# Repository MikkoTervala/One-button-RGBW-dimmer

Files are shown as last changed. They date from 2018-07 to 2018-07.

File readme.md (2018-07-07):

This dimmer was built for a car. It uses a single button to cycle between colors. 
Other features include:

- 6 RGBW outputs.
- Individually fused channels, 4 polyfuses for each output, 24 fuses in total.
- OTA update over wifi, starts to OTA mode by holding button while starting car.

Microcontroller is the ESP8266 and code is written in arduino. Kicad is used for the PCB design.

Imgur

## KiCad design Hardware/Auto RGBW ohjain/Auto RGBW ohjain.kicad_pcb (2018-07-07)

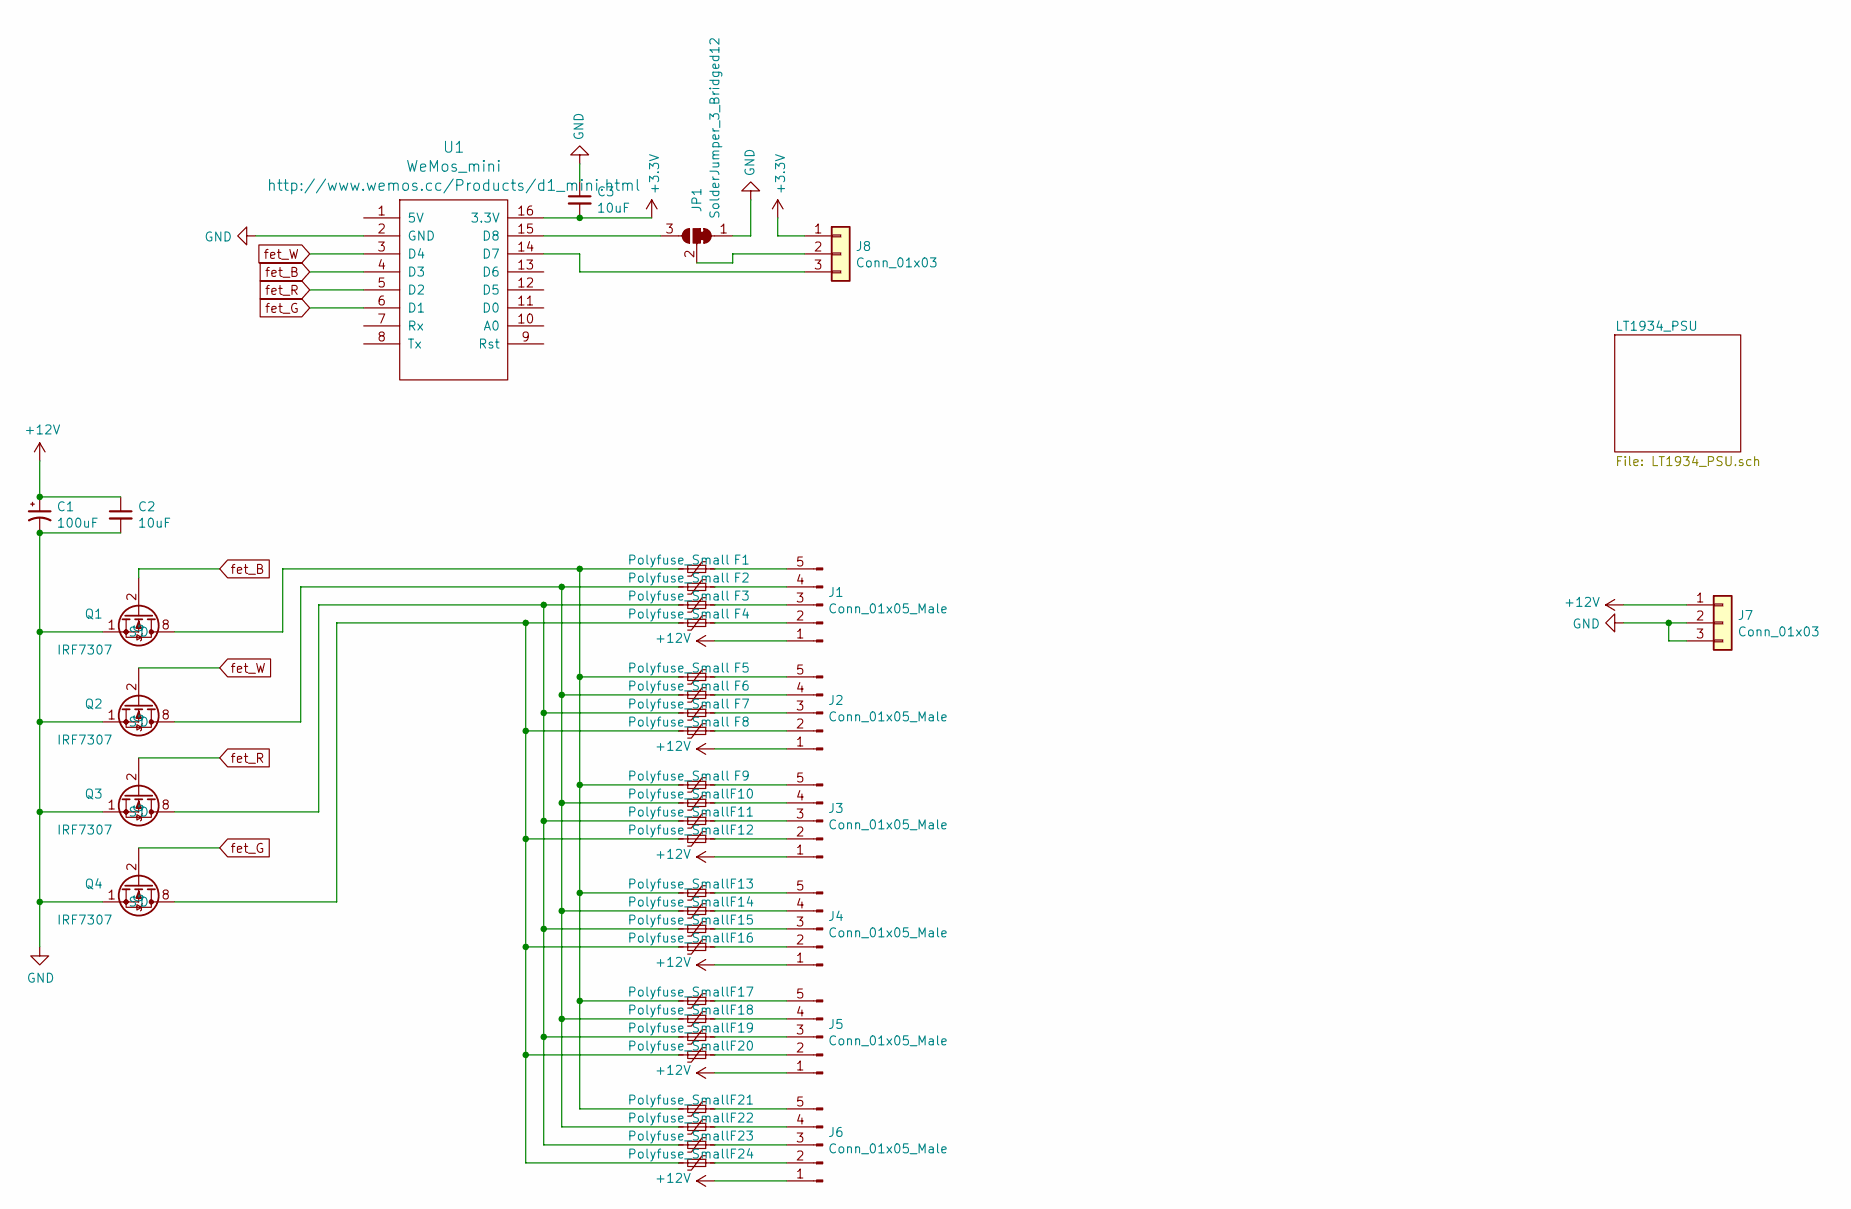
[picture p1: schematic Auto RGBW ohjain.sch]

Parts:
C1: 100uF; CP_Radial_D6.3mm_P2.50mm
C2, C3: 10uF; C_1210_3225Metric
F1, F2, F3, F4, F5, F6, F7, F8, F9, F10, F11, F12, F13, F14, F15, F16, F17, F18, F19, F20, F21, F22, F23, F24: Polyfuse_Small; Fuse_1206_3216Metric; Manufacture Part Number 1206L035/16YR; LCSC Part Number C126817
J1, J2, J3, J4, J5, J6: Conn_01x05_Male; JST_XH_B05B-XH-A_1x05_P2.50mm_Vertical
J7, J8: Conn_01x03; WJ250B-3.50-3P
JP1: SolderJumper_3_Bridged12; SolderJumper-3_P1.3mm_Bridged12_RoundedPad1.0x1.5mm
Q1, Q2, Q3, Q4: IRF7307; SO-8_5.3x6.2mm_P1.27mm
U1: WeMos_mini; D1_mini_board

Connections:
+3V3: C3.2, J8.1, U1.16 (3.3V); also elsewhere on the board
+12V: C1.1, C2.1, J1.1, J2.1, J3.1, J4.1, J5.1, J6.1, J7.1; also elsewhere on the board
GND: C1.2, C2.2, C3.1, J7.2, J7.3, JP1.1 (A), Q1.1 (S), Q2.1 (S), Q3.1 (S), Q4.1 (S), U1.2 (GND); also elsewhere on the board
unnamed: F1.1, J1.5
unnamed: F1.2, F5.2, F9.2, F13.2, F17.2, F21.2, Q1.7 (D), Q1.8 (D)
unnamed: F2.1, J1.4
unnamed: F3.1, J1.3
unnamed: F4.1, J1.2
unnamed: F5.1, J2.5
unnamed: F6.1, J2.4
unnamed: F7.1, J2.3
unnamed: F8.1, J2.2
unnamed: F9.1, J3.5
unnamed: F10.1, J3.4
unnamed: F2.2, F6.2, F10.2, F14.2, F18.2, F22.2, Q2.7 (D), Q2.8 (D)
unnamed: F11.1, J3.3
unnamed: F3.2, F7.2, F11.2, F15.2, F19.2, F23.2, Q3.7 (D), Q3.8 (D)
unnamed: F12.1, J3.2
unnamed: F4.2, F8.2, F12.2, F16.2, F20.2, F24.2, Q4.7 (D), Q4.8 (D)
unnamed: F13.1, J4.5
unnamed: F14.1, J4.4
unnamed: F15.1, J4.3
unnamed: F16.1, J4.2
unnamed: F17.1, J5.5
unnamed: F18.1, J5.4
unnamed: F19.1, J5.3
unnamed: F20.1, J5.2
unnamed: F21.1, J6.5
unnamed: F22.1, J6.4
unnamed: F23.1, J6.3
unnamed: F24.1, J6.2
unnamed: J8.2, JP1.2 (C)
unnamed: J8.3, U1.14 (D7)
unnamed: JP1.3 (B), U1.15 (D8)
fet_B: Q1.2 (G), U1.4 (D3)
fet_G: Q4.2 (G), U1.6 (D1)
fet_R: Q3.2 (G), U1.5 (D2)
fet_W: Q2.2 (G), U1.3 (D4)

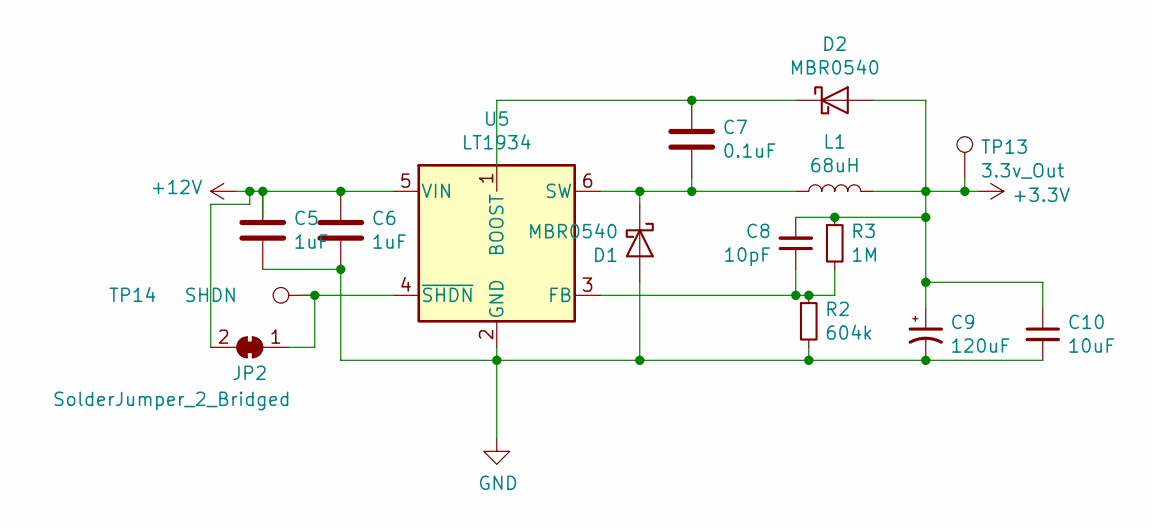
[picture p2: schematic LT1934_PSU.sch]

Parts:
C5, C6: 1uF; C_1206_3216Metric
C7: 0.1uF; C_0805_2012Metric; Manufacture Part Number GRM2165C2A101JA01D; LCSC Part Number C97903
C8: 10pF; C_0805_2012Metric
C9: 120uF; CP_Radial_D6.3mm_P2.50mm
C10: 10uF; C_1210_3225Metric
D1, D2: MBR0540; D_SOD-123; Manufacture Part Number MBR0540L-CA2-R; LCSC Part Number C89706
JP2: SolderJumper_2_Bridged; SolderJumper-2_P1.3mm_Bridged_RoundedPad1.0x1.5mm
L1: 68uH; L_SUMIDA_CDRH5D28
R2: 604k; R_0805_2012Metric; Manufacture Part Number 0805W8F6043T5E; LCSC Part Number C17776
R3: 1M; R_0805_2012Metric; Manufacture Part Number 0805W8F1004T5E; LCSC Part Number C17514
TP13: 3.3v_Out; TestPoint_Loop_D2.50mm_Drill1.0mm
TP14: SHDN; TestPoint_Pad_D1.0mm
U5: LT1934; SOT-23-6

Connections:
+3V3: C8.2, C9.1, C10.1, D2.2 (A), L1.2, R3.1, TP13.1; also elsewhere on the board
+12V: C5.2, C6.2, JP2.2 (B), U5.5 (VIN); also elsewhere on the board
GND: C5.1, C6.1, C9.2, C10.2, D1.2 (A), R2.2, U5.2 (GND); also elsewhere on the board
unnamed: C7.1, D2.1 (K), U5.1 (BOOST)
unnamed: C7.2, D1.1 (K), L1.1, U5.6 (SW)
unnamed: C8.1, R2.1, R3.2, U5.3 (FB)
unnamed: JP2.1 (A), TP14.1, U5.4 (~SHDN)

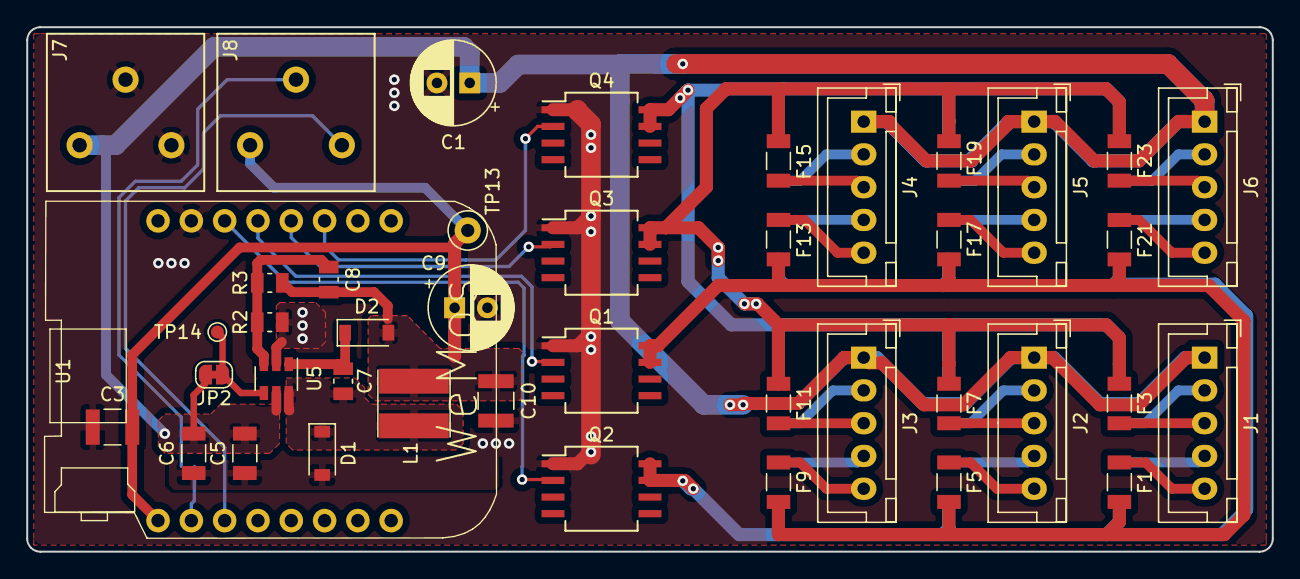
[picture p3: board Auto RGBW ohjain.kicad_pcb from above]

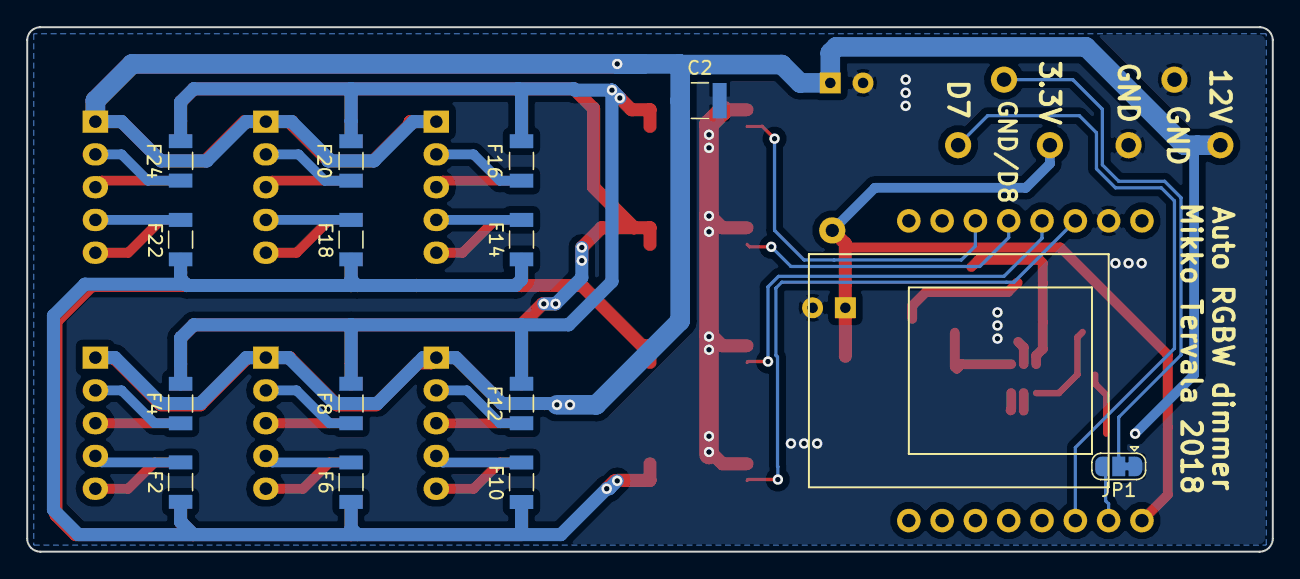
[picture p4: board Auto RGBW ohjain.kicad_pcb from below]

Board: 2 copper layers, 95.0 x 40.0 mm, 56 parts (14 on the bottom side), 42 nets.

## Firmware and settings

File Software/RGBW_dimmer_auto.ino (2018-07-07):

#include <ESP8266WiFi.h>
#include <ESP8266mDNS.h>
#include <WiFiUdp.h>
#include <ArduinoOTA.h>

// Wifi credentials for OTA update
const char* ssid = "WIFI SSID for OTA";
const char* password = "PASSWORD";


#define R D2
#define G D1
#define B D3
#define W D4
#define button D7

int RGBWarray[4] = { 500, 500, 500, 500 };	// Brightness we want to display
int RGBWarrayReal[4] = { 0, 0, 0, 0 };		// Actual pwm value at the moment

bool onOff = 1;			// Is light on or off
int colorSelect = 0;	// Selected color number

long buttonTimer = 0;
long longPressTime = 400;
boolean buttonActive = false;
boolean longPressActive = false;
boolean singlePress = false;
boolean longPress = false;

unsigned long dimmerPreviousMillis = 0;
const long dimmerInterval = 0;

// Writes PWM values, used in debugging without dimming
void debugWritePwm()
{
	analogWrite(R, RGBWarray[0]);
	analogWrite(G, RGBWarray[1]);
	analogWrite(B, RGBWarray[2]);
	analogWrite(W, RGBWarray[3]);
}

// Writes PWM values
void writePwm() 
{
	analogWrite(R, RGBWarrayReal[0]);
	analogWrite(G, RGBWarrayReal[1]);
	analogWrite(B, RGBWarrayReal[2]);
	analogWrite(W, RGBWarrayReal[3]);
}

// This checks if we want to change the brightness of any channel, and changes the value smoothly if needed
void dimmer()
{
	unsigned long currentMillis = millis();
	if (currentMillis - dimmerPreviousMillis >= dimmerInterval)
	{
		dimmerPreviousMillis = currentMillis;
		for (int i = 0; i <= 3; i++)
		{
			if (RGBWarray[i] > RGBWarrayReal[i])
			{
				RGBWarrayReal[i] ++;
			}
			if (RGBWarray[i] < RGBWarrayReal[i])
			{
				RGBWarrayReal[i] --;
			}
		}
		writePwm();
	}
}

// Checks if any buttons pressed, and updates statuses
void buttonPress()
{
	longPress = false;
	singlePress = false;

	if (digitalRead(button) == HIGH) {
		//Serial.println("Button pressed");
		if (buttonActive == false) {
			buttonActive = true;
			buttonTimer = millis();
		}
		if ((millis() - buttonTimer > longPressTime) && (longPressActive == false)) {
			longPressActive = true;
			longPress = true;
		}
	}
	else {
		if (buttonActive == true) {
			Serial.println("2");
			if (longPressActive == true) {
				longPressActive = false;
			}
			else {
				singlePress = true;
			}
			buttonActive = false;
		}
	}
}

// Ota mode waits for ota software update
void otaMode()
{
	Serial.begin(115200);
	Serial.println("Booting");
	WiFi.mode(WIFI_STA);
	WiFi.begin(ssid, password);
	while (WiFi.waitForConnectResult() != WL_CONNECTED) {
		Serial.println("Connection Failed! Rebooting...");
		delay(5000);
		ESP.restart();
	}
	// Port defaults to 8266
	// ArduinoOTA.setPort(8266);

	// Hostname defaults to esp8266-[ChipID]
	// ArduinoOTA.setHostname("myesp8266");

	// No authentication by default
	// ArduinoOTA.setPassword("admin");

	// Password can be set with it's md5 value as well
	// MD5(admin) = 21232f297a57a5a743894a0e4a801fc3
	// ArduinoOTA.setPasswordHash("21232f297a57a5a743894a0e4a801fc3");

	ArduinoOTA.onStart([]() {
		String type;
		if (ArduinoOTA.getCommand() == U_FLASH)
			type = "sketch";
		else // U_SPIFFS
			type = "filesystem";

		// NOTE: if updating SPIFFS this would be the place to unmount SPIFFS using SPIFFS.end()
		Serial.println("Start updating " + type);
	});
	ArduinoOTA.onEnd([]() {
		Serial.println("\nEnd");
		RGBWarray[0] = 100;
		RGBWarray[1] = 800;
		RGBWarray[2] = 100;
		RGBWarray[3] = 100;
		debugWritePwm();
		delay(2000);
	});
	ArduinoOTA.onProgress([](unsigned int progress, unsigned int total) {
		Serial.printf("Progress: %u%%\r", (progress / (total / 100)));
		RGBWarray[0] = 100;
		RGBWarray[1] = 100;
		RGBWarray[2] = 800;
		RGBWarray[3] = 100;
		debugWritePwm();
		delay(200);
	});
	ArduinoOTA.onError([](ota_error_t error) {
		Serial.printf("Error[%u]: ", error);
		if (error == OTA_AUTH_ERROR) Serial.println("Auth Failed");
		else if (error == OTA_BEGIN_ERROR) Serial.println("Begin Failed");
		else if (error == OTA_CONNECT_ERROR) Serial.println("Connect Failed");
		else if (error == OTA_RECEIVE_ERROR) Serial.println("Receive Failed");
		else if (error == OTA_END_ERROR) Serial.println("End Failed");
		RGBWarray[0] = 800;
		RGBWarray[1] = 100;
		RGBWarray[2] = 100;
		RGBWarray[3] = 100;
		debugWritePwm();
		delay(2000);
	});
	ArduinoOTA.begin();
	Serial.println("Ready");
	Serial.print("IP address: ");
	Serial.println(WiFi.localIP());

	while (true)
	{
		Serial.println("Ota loop");
		//delay(500);
		ArduinoOTA.handle();
		RGBWarray[0] = 200;
		RGBWarray[1] = 200;
		RGBWarray[2] = 200;
		RGBWarray[3] = 200;
		debugWritePwm();
		delay(500);
		RGBWarray[0] = 10;
		RGBWarray[1] = 10;
		RGBWarray[2] = 10;
		RGBWarray[3] = 10;
		debugWritePwm();
		delay(500);
		if (digitalRead(button) == HIGH)
		{
			delay(500);
			if (digitalRead(button) == HIGH)
			{
				RGBWarray[0] = 800;
				RGBWarray[1] = 100;
				RGBWarray[2] = 100;
				RGBWarray[3] = 100;
				debugWritePwm();
				delay(2000);
				ESP.restart();
			}
		}
	}
}



void setup()
{
	Serial.begin(115200);
	delay(2000);
	Serial.println("Started");
	pinMode(R, OUTPUT);
	pinMode(G, OUTPUT);
	pinMode(B, OUTPUT);
	pinMode(W, OUTPUT);
	pinMode(button, INPUT);
	delay(500);
	if (digitalRead(button) == HIGH)
	{
		Serial.println("Ota mode!");
		delay(500);
		otaMode();
	}
}

void loop()
{
	dimmer();
	buttonPress();

	if (singlePress)
	{
		Serial.println("single press true");
		colorSelect++;
		if (colorSelect > 4)
		{
			colorSelect = 0;
		}
		Serial.println(colorSelect);
	}
	if (longPress)
	{
		onOff = !onOff;
	} 

	switch (colorSelect)
	{
	case 0:
		RGBWarray[0] = 1000;
		RGBWarray[1] = 0;
		RGBWarray[2] = 1000;
		RGBWarray[3] = 500;
		break;
	case 1:
		RGBWarray[0] = 200;
		RGBWarray[1] = 0;
		RGBWarray[2] = 200;
		RGBWarray[3] = 100;
		break;
	case 2:
		RGBWarray[0] = 1000;
		RGBWarray[1] = 0;
		RGBWarray[2] = 0;
		RGBWarray[3] = 100;
		break;
	case 3:
		RGBWarray[0] = 0;
		RGBWarray[1] = 0;
		RGBWarray[2] = 1000;
		RGBWarray[3] = 300;
		break;
	case 4:
		RGBWarray[0] = 0;
		RGBWarray[1] = 0;
		RGBWarray[2] = 0;
		RGBWarray[3] = 500;
		break;
	default:
		break;
	}

	if (onOff)
	{
		RGBWarray[0] = 0;
		RGBWarray[1] = 0;
		RGBWarray[2] = 0;
		RGBWarray[3] = 0;
	}
}
